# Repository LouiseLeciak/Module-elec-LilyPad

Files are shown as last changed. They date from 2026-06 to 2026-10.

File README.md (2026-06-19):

# Lily's Pad

## Overview

Lily's Pad is a simple interactive and educational object primarily intended for
children, teachers/educational teams, and families

It allows users to familiarize themselves with the alphabet and numbers in
French Sign Language (FSL) or English Sign Language (ESL), as chosen.

Lily's Pad is also accessible for hearing users who are curious or who have
hearing-impaired loved ones they would like to communicate with.

## I. Features

An LCD screen connected to a keyboard featuring letters and numbers.
A rotary encoder allowing users to scroll through FSL/ASL signs on the screen.
A clickable rotary encoder to confirm an input.
A USB Type-C port to power the device.
A power button to turn the device on/off.
A 3D-printed casing around the screen.
A 3D-printed base in which the keyboard is embedded.
A slide switch to change language, English (ASL) or French (FSL).
Two small LCD screens to display animated eyes.
Translation/game/alphabet modes.

## How to use this repository

### Generate Doxygen static website

Run the following command:

```
make doc
```

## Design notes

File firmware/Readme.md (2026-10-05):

ENGLISH VERSION BELOW

# Application principale

=================================

## Presentation

Cette application est un projet embarque developpe sur un ATmega2560.

Elle permet à l'utilisateur d'apprendre et de manipuler les signes de la LSF (Langue des Signes Française) et de la BSL (British Sign Language) grâce à une interface composee de 3 ecrans, d'un clavier matriciel et d'un encodeur rotatif.

L'application possede trois fonctionnalites principales :

- Traduction
- Alphabet
- Jeu

## Fonctionnement general

Au demarrage, le microcontrôleur initialise les differents peripheriques :

1. Les ecrans
2. Le clavier matriciel
3. Le MCP23017 lie a l'encodeur rotatif
4. Le systeme de selection de langue
5. Les differents etats de l'application

Une fois l'initialisation terminee, le menu principal est affiche.

L'application fonctionne ensuite dans une boucle principale qui verifie continuellement :

- le changement de langue.
- la rotation de l'encodeur.
- l'appui sur le bouton de l'encodeur.
- l'activite du clavier.
- le systeme d'economie d'energie .
- l'etat actuel de l'application.

Le comportement de l'interface depend principalement de machines à etats.

## Materiel

Le projet utilise principalement :

- ATmega2560 : microcontrôleur principal

- ILI9488 : ecran principal

- 2 × GC9A01 : ecrans utilises pour les yeux

- MCP23017 : pour parler en i2c au rotary encoder

- encodeur rotatif : navigation et selection

- Clavier matriciel 4 × 10 : saisie de caracteres

- Carte SD : stockage des images

- Switch : selection de la langue

## Menu principal

> Le menu principal contient trois choix :

> - Traduction

> - Alphabet

> - Jeu

L'encodeur permet de deplacer le curseur.

Le bouton permet de selectionner l'element choisi.

Le choix actuel est stocke dans menu_choice.

### Traduction

La fonctionnalite de traduction permet de saisir un mot à l'aide du clavier.

**Fonctionnement :**

- Entrer dans Traduction

- Saisir un mot

- Valider avec l'encodeur

- Afficher le signe de la premiere lettre

- Appuyer pour passer à la lettre suivante

- Afficher le signe suivant

- Continuer jusqu'à la derniere lettre

- Revenir à une nouvelle saisie

Le mot est stocke dans word et sa longueur dans word_len.

La touche “delete” permet de supprimer le dernier caractere.

Lorsque le mot est valide, le programme recherche les images correspondant aux differentes lettres sur la carte SD.

Les images dependent de la langue selectionnee.

Pour la LSF, le programme recherche les images associees au suffixe LSF.

Pour la BSL, le programme recherche les images associees au suffixe BSL.

Les images sont ensuite affichees une par une sur l'ecran principal.

----------------------------------------------------------------------
### Alphabet

La fonctionnalite Alphabet permet de parcourir les caracteres disponibles.

L'utilisateur utilise l'encodeur pour se deplacer dans la liste.

Un appui sur le bouton permet d'afficher la lettre selectionnee.

Un nouvel appui permet de revenir à la liste.

**Les deux principaux etats sont :**

ALPHABET_LIST

ALPHABET_LETTER

----------------------------------------------------------------------
### Jeux

L'application possede deux jeux.

**Jeu 1 : trouver la bonne lettre**

Le premier jeu consiste à reconnaître une lettre à partir d'un signe.

Le programme choisit aleatoirement une lettre et affiche le signe correspondant.

L'utilisateur doit ensuite choisir la bonne lettre parmi trois propositions.

Deroulement :

Signe affiche

3 propositions

Selection avec l'encodeur

Validation avec le bouton

Affichage de OUI ou NON

Une seule des trois reponses correspond au signe affiche.

Si la reponse est correcte, une nouvelle question est generee.

Si la reponse est incorrecte, le jeu revient à l'ecran de depart du jeu.

**Jeu 2 : trouver le bon signe**

Le fonctionnement est inverse.

Le programme choisit une lettre et l'affiche.

Trois signes sont ensuite presentes successivement.

Deroulement :

Lettre affichee

Signe 1

Signe 2

Signe 3

Choix entre 1, 2 et 3

Validation avec le bouton

Affichage de OUI ou NON

Une seule des trois images correspond à la lettre donnee.

Les choix et les lettres sont generes aleatoirement.

----------------------------------------------------------------------
## Encodeur rotatif

L'encodeur est connecte au MCP23017, lui-meme relie à l'ATmega2560 par I²C.

Il possede trois signaux :

**CLK** : rotation

**DT** : direction

**SW** : bouton

La rotation permet de deplacer les curseurs dans les differents menus.

Le bouton permet de valider ou de passer à l'etape suivante.

Le comportement de l'encodeur depend de l'etat actuel de l'application.

Par exemple :

Dans le MENU, l'encodeur deplace le curseur du menu.

Dans l'ALPHABET, il permet de parcourir les lettres.

Dans le JEU, il permet de sectelionner une reponse.

Le bouton possede egalement un systeme d'anti-rebond afin d'eviter plusieurs detections pour un seul appui.

## Clavier

Le clavier est une matrice de 4 lignes et 10 colonnes, soit 38 touches.

La disposition utilisee est :

1 2 3 4 5 6 7 8 9 0

Q W E R T Y U I O P

A S D F G H J K L -

Z X C V B N M # /

Le '#' est pour le retour a l'ecran principal, '/' pour supprimer.

Le programme selectionne chaque ligne successivement et lit les colonnes afin de detecter la touche appuyee.

Le tableau keymap permet ensuite de convertir la position de la touche en caractere.

## Gestion de la langue

Deux langues sont disponibles :

LANG_FR

LANG_EN

La langue est selectionnee grâce à un switch materiel.

La variable language permet de connaître la langue actuellement utilisee.

Les textes affiches et les images recherchees dependent de cette langue.

## Gestion de l'energie

L'application possede un systeme d'economie d'energie.

Lorsqu'aucune interaction n'est detectee pendant un certain temps, l'application passe en veille.

Le retroeclairage de l'ecran principal est alors desactive et les yeux changent d'affichage.

Une activite de l'utilisateur reactive le systeme.

Les principales actions considerees comme une activite sont :

- rotation de l'encodeur
- appui sur le bouton
- appui sur une touche du clavier
- changement de langue

La fonction power_save_activity() remet le systeme en activite.

La fonction power_save_update() gere le compteur d'inactivite, apres une 20aine de secondes on passe en economie d’energie.

### Architecture du code

Le projet est organise en plusieurs modules.

Le dossier app contient la logique principale de l'application :

- menu

- traduction

- alphabet

- game

Le dossier display contient la gestion des ecrans :

- ILI9488

- GC9A01

- affichage du texte

Le dossier input contient la gestion des entrees :

- clavier

- encodeur

- I²C / MCP23017

Le dossier system contient les elements communs au systeme :

- globals

- power_save

- Le dossier utils contient les fonctions utilitaires.

- Chaque module possede une responsabilite specifique.

- Les modules app gerent la logique de l'application.

- Les modules input gerent les interactions avec l'utilisateur.

- Les modules display gerent les ecrans.

- Les modules system regroupent les elements communs au fonctionnement du systeme.

- Machine à etats

- Le fonctionnement de l'application repose sur plusieurs niveaux d'etats.

- L'etat principal est app_state.

Il permet de savoir si l'utilisateur se trouve dans :

MENU

TRADUCTION

ALPHABET

JEU

Chaque fonctionnalite possede ensuite ses propres etats.

Par exemple, pendant un jeu :

- Afficher la question

- Afficher les propositions

- Selectionner une reponse

- Valider

- Afficher OUI ou NON

- Passer à la question suivante

Cette organisation permet au meme bouton ou au meme mouvement de l'encodeur d'avoir un comportement different selon la situation.

## Boucle principale

La boucle principale permet à l'application de surveiller en permanence les entrees utilisateur et de faire evoluer la machine à etats.

Elle gere notamment :

- la langue

- le generateur aleatoire 

- l'encodeur 

- le bouton de l'encodeur 

- l'economie d'energie 

- le clavier 

- la fonctionnalite actuellement selectionnee.

## Resume

L'application est organisee autour de trois elements principaux.

**Entrees :**

- Clavier matriciel

- Encodeur rotatif

- Bouton de l'encodeur

- Switch de langue

**Traitement :**

- Machines à etats

- Navigation dans les menus

- Gestion de la traduction

- Gestion de l'alphabet

- Gestion des jeux

- Generation aleatoire

- Gestion de l'economie d'energie

**Sorties :**

- Ecran ILI9488

- Deux ecrans GC9A01

- Images de signes stockees sur carte SD

Le systeme utilise principalement une architecture basee sur les etats. Cela permet de gerer les differentes fonctionnalites de l'application et d'adapter le comportement du clavier, de l'encodeur et du bouton en fonction de l'ecran ou de l'action en cours.

-------------------------------------------------------------------------------------------------------

# Primary Application

=================================

## Presentation

This application is a project developed on an ATmega2560.

It allows the user to learn and manipulate the signs of LSF (French Sign Language) and BSL (British Sign Language) thanks to an interface composed of 3 screens, a matrix keyboard and a rotary encoder.

The application has three main functionalities:

- Translation
- Alphabet
- Game

## General operation

At startup, the microcontroller initializes the different devices:

1. The screens
2. The matrix keyboard
3. The MCP23017 is connected to the rotary encoder
4. The language selection system
5. The different states of the application

Once the initialization is complete, the main menu appears.

The application then runs in a main loop that continuously checks:

- the change of language.
- the encoder rotation.
- pressing the encoder button.
- the keyboard activity.
- the energy-saving system.
- the current status of the application.

The behavior of the interface mainly depends on state machines.

## Hardware

The project mainly uses:

- ATmega2560: Primary microcontroller

- ILI9488: main screen

- 2 × GC9A01: screens used for the eyes

- MCP23017: to speak in i2c at the rotary encoder

- rotary encoder: navigation and selection

- Matrix keyboard 4 × 10: character input

- SD card: image storage

- Switch: language selection

## Main Menu

> The main menu contains three choices:

> - Translation

> - Alphabet

> - Game

The encoder allows you to move the cursor.

The button allows you to select the chosen element.

The current choice is stored in menu_choice.

### Translation

Translation functionality allows you to enter a word using the keyboard.

**Operation:***

- Enter Translation

- Enter a word

- Validate with the encoder

- Display the sign of the first letter

- Press to move on to the next letter

- Display the following sign

- Continue until the last letter

- Return to a new entry

The word is stored in word and its length in word_len.

The key "delete" allows to delete the last character.

When the word is valid, the program searches for images corresponding to the different letters on the SD card.

The images dependent on the selected language.

For LSF, the program searches for images associated with the LSF suffix.

For the BSL, the program searches for images associated with the BSL suffix.

The images are then displayed one by one on the main screen.

----------------------------------------------------------------------
### Alphabet

The Alphabet functionality allows you to browse through the available characters.

The user uses the encoder to move into the list.

Pressing the button displays the selected letter.

A new tap allows you to return to the list.

**The two main states are:***

ALPHABET_LIST

ALPHABET_LETTER

----------------------------------------------------------------------
### Games

The app has two games.

**Game 1: find the right letter**

The first game is to recognize a letter from a sign.

The program randomly chooses a letter and displays the corresponding sign.

The user must then choose the correct letter from among three proposals.

Layout:

Poster sign

3 proposals

Selection with the encoder

Validation with the button

Display YES or NO

Only one of the three answers corresponds to the poster sign.

If the answer is correct, a new question is generated.

If the answer is incorrect, the game returns to the game’s start screen.

**Game 2: find the right sign**

The operation is reversed.

The program chooses a letter and displays it.

Three signs are then presented successively.

Layout:

Letter displayed

Sign 1

Sign 2

Sign 3

Choice between 1, 2, and 3

Validation with the button

Display YES or NO

Only one of the three images corresponds to the given letter.

Choices and letters are randomly generated.

----------------------------------------------------------------------
## Rotary encoder

The encoder is connected to the MCP23017, which in turn is connected to the ATmega2560 by I 2 C.

He has three signals:

**CLK** : rotation

**DT** : management

**SW** : button

Rotation allows you to move the cursors in different menus.

The button allows you to validate or move on to the next step.

The encoder behavior depends on the current state of the application.

For example:

In the MENU, the encoder moves the menu cursor.

In the ALPHABET, it allows you to move through the letters.

In the GAME, it allows you to select a response.

The button also has an anti-bounce system to avoid several detections for a single touch.

## Keyboard

The keyboard is a matrix of 4 rows and 10 columns, or 38 keys.

The layout used is:

1 2 3 4 5 6 7 8 9 0

Q W E R T Y U I O P

A S D F G H J K L

Z X C V B N M # /

'#' is for HOME and '/' is for delete.

The program selects each row successively and reads the columns in order to detect the key pressed.

The keymap table then allows you to convert the key position into a character.

## Language Management

Two languages are available:

LANG_FR

LANG_EN

The language is selected thanks to a hardware switch.

The language variable lets you know which language is currently in use.

The poster texts and images sought after in this language.

## Energy Management

The application has an energy-saving system.

When no interaction is detected for a period of time, the application goes into standby.

The backlighting of the main screen is then deactivated and the eyes change their display.

An activity of the user reactivates the system.

The main actions considered as an activity are:

- rotation of the encoder
- press the button
- press a key on the keyboard
- change of language

The power_save_activity() function restarts the system.

The power_save_update() function manages the inactivity counter, after about 20 seconds you switch to power saving.

### Code Architecture

The project is organized into several modules.

The app folder contains the main logic of the application:

- menu

- translation

- alphabet

- game

The display folder contains screen management:

- ILI9488

- GC9A01

- displaying the text

The input folder contains the management of entries:

- keyboard

- encoder

- I 2 C / MCP23017

The system folder contains the common elements of the system:

- globals

- power_save

- The utils folder contains the utility functions.

- Each module has a specific responsibility.

- The app modules manage the logic of the application.

- The input modules manage interactions with the user.

- The display modules handle the screens.

- The system modules bring together the common elements of the system’s operation.

- State machine

- The operation of the application is based on several levels of states.

- The main state is app_state.

It lets you know if the user is located in:

**MENU**

**TRANSLATION**

**ALPHABET**

**GAME**

Each functionality then has its own states.

For example, during a game:

- View the question

- View the proposals

- Select a response

- Validate

- Show YES or NO

- Move on to the next question

This organization allows the same button or the same movement of the encoder to have a different behavior depending on the situation.

## Main loop

The main loop allows the application to constantly monitor user inputs and to make the state machine evolve.

She manages in particular:

- the language

- the random generator 

- the encoder 

- the encoder button 

- energy saving 

- the keyboard 

- the functionality currently selected.

## Resume

The application is organized around three main elements.

**Entries:**

- Matrix keyboard

- Rotary encoder

- Encoder button

- Switch language

**Treatment:**

- State machines

- Menu navigation

- Translation management

- Management of the alphabet

- Game management

- Random generation

- Energy saving management

**Outings:**

- Screen ILI9488

- Two GC9A01 screens

- Sign images stored on an SD card

The system mainly uses a state-based architecture. This allows to manage the different functionalities of the application and to adapt the behavior of the keyboard, the encoder and the button according to the screen or the current action.

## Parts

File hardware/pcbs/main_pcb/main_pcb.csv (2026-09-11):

Reference | Qty | Value | DNP | Exclude from BOM | Exclude from Board | Footprint | Datasheet
C1,C2,C5,C6,C7,C21,C22,C23,C24,C25,C26,C27,C28,C29,C30,C31,C32,C33 | 18 | 100nF
C3,C4 | 2 | 33pF
C8,C9 | 2 | 0.1uF
C20 | 1 | 10uF
J1,J3,S2,U1,U15,U17,Y1 | 7 | ~ |  |  |  |  | file:///Users/apetitco/Documents/Module Elec - Lily's Pad/Datasheets/U - Integrated Circuits/MCU/ATmega_2560.pdf,file:///Users/apetitco/Documents/Module Elec - Lily's Pad/Datasheets/U - Integrated Circuits/Screen Drivers/GC9A01A.pdf,file:///Users/apetitco/Documents/Module Elec - Lily's Pad/Datasheets/Y - Crystals and Oscillators/SOSET_S47SMD16.000M20PF20R30B3.pdf
J2 | 1 | USB-C |  |  |  |  | file:///Users/apetitco/Documents/Module Elec - Lily's Pad/Datasheets/U - Integrated Circuits/Voltage Regulators/JSMSEMI_AMS1117-3.3V.pdf
J4 | 1 | 2X4 Header
R1,R8,R9,R10,R11 | 5 | 10kΩ
R2,R3 | 2 | 5.1kΩ
U8 | 1 | CH340C |  |  |  | lilys_pad:CH340C | file:///Users/apetitco/Documents/Module Elec - Lily's Pad/Datasheets/U - Integrated Circuits/CH340C.pdf
U10 | 1 | JSMSEMI AMS1117-3.3V |  |  |  |  | file:///Users/apetitco/Documents/Module Elec - Lily's Pad/Datasheets/U - Integrated Circuits/Voltage Regulators/JSMSEMI_AMS1117-3.3V.pdf
U11,U13,U16 | 3 | TI TXB0104DR |  |  |  |  | file:///home/apetitco/Documents/school/42Chips/module/Datasheets/U - Integrated Circuits/Level Shifters/7ebf70d32255e71aa643aae8d62d2a45.pdf
U12 | 1 | ILI9488
U14 | 1 | SD Card Socket

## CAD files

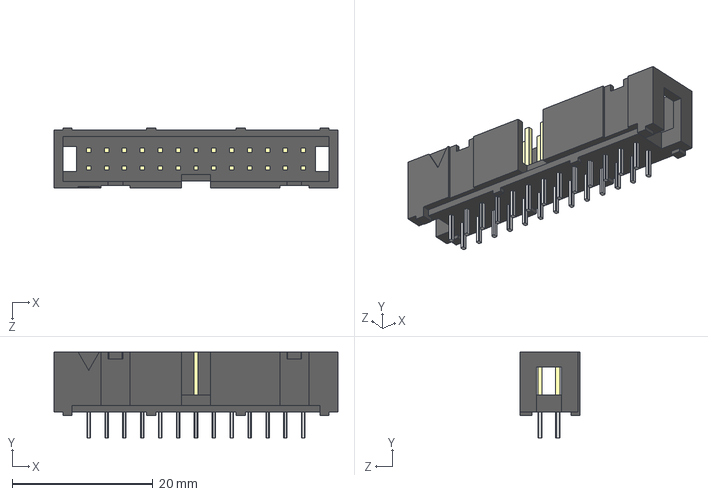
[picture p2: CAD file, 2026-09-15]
hardware/kicad_libraries/3D Models/XG4C-2631--3DModel-STEP-273799.STEP
40.3 x 12.2 x 8.50 mm

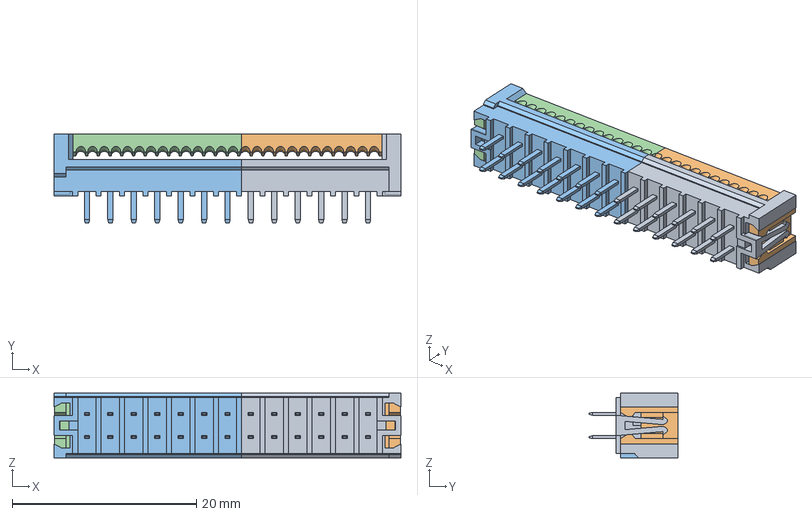
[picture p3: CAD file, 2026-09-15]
hardware/kicad_libraries/3D Models/69830-026LF--3DModel-STEP-533217.STEP
37.6 x 9.65 x 7.00 mm
69830_20P_BODY_1_AF0_1_AF0_1
69830_20P_COVER_1_AF0_1_AF0_1
69830_20P_BODY_1_AF0_1
69830_20P_COVER_1_AF0_1

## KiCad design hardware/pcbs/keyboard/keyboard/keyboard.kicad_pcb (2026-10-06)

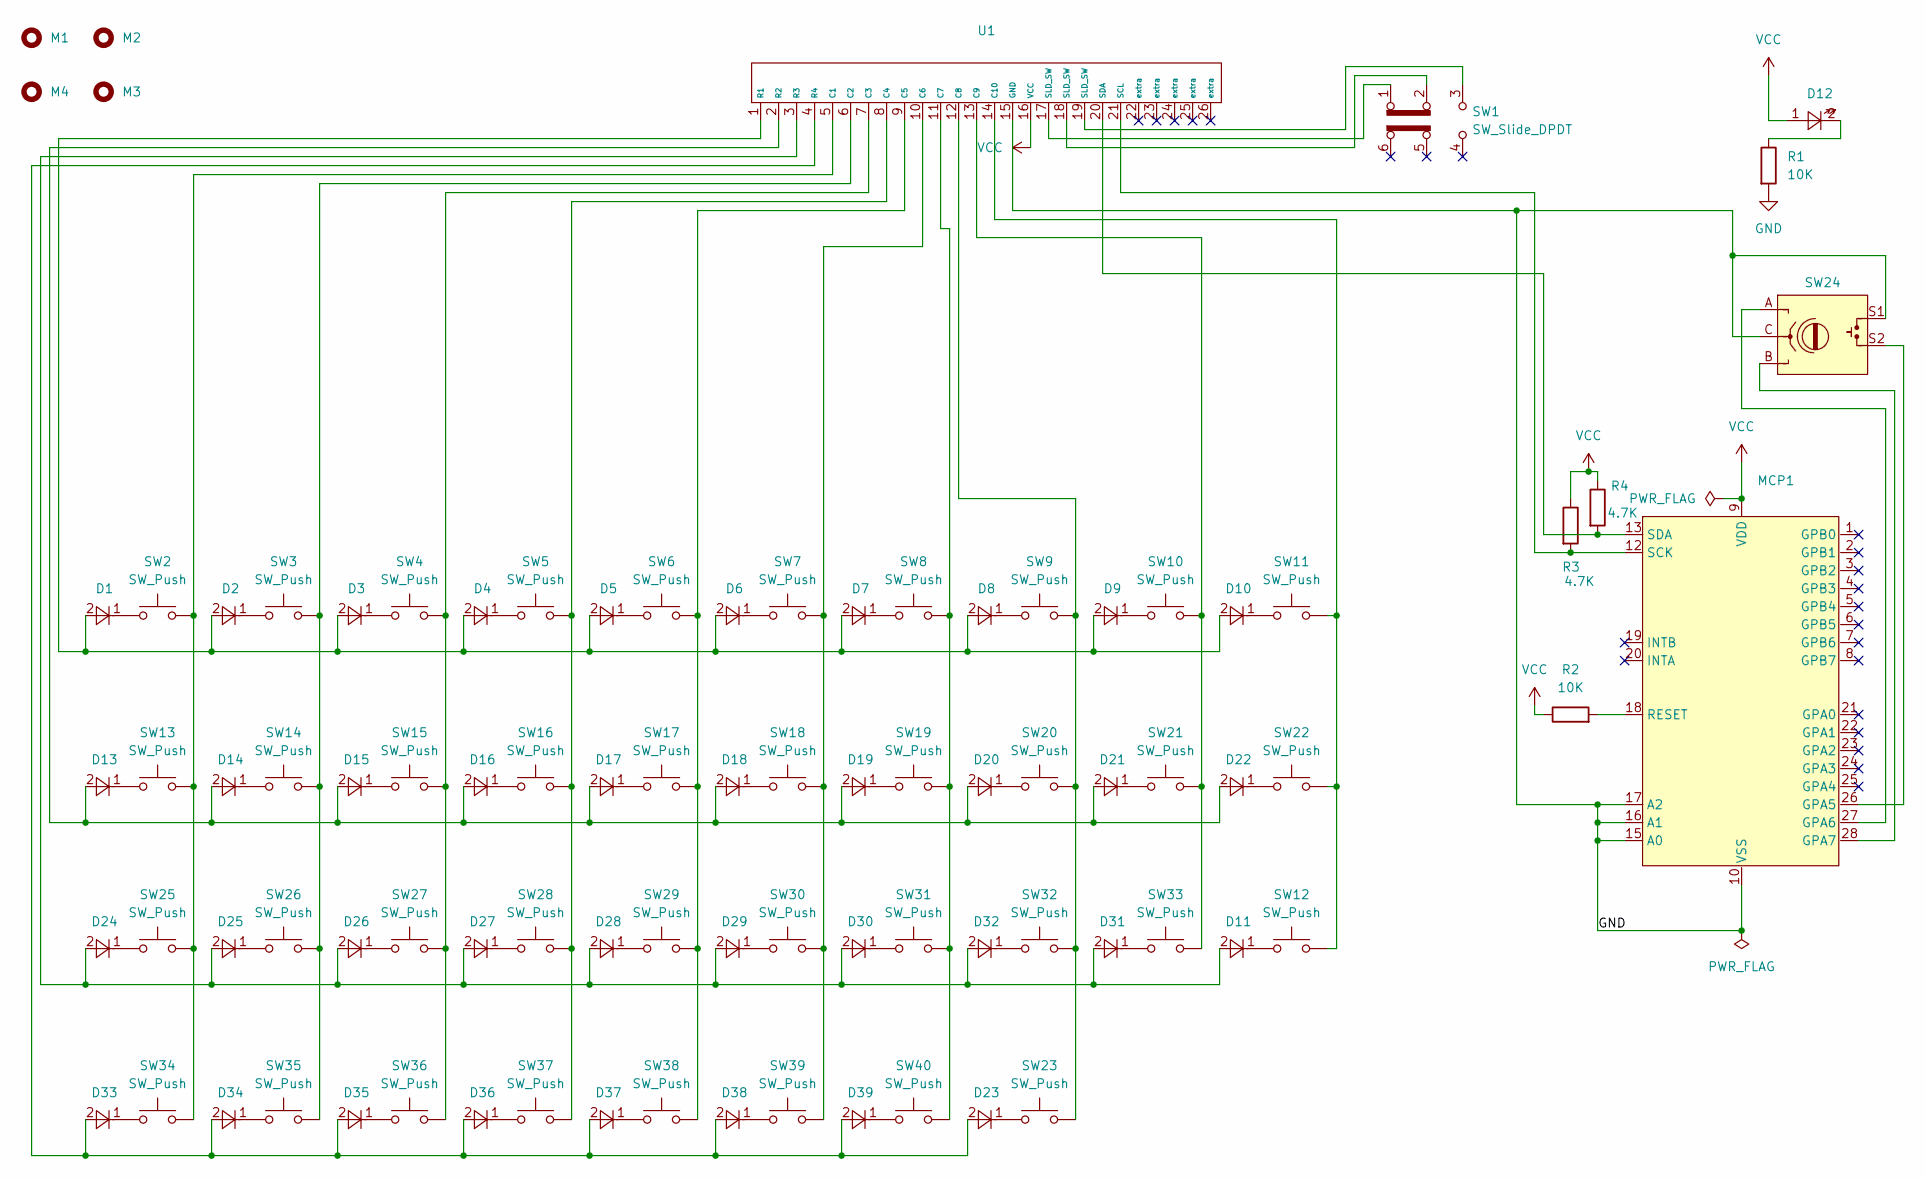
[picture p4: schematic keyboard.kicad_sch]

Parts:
D1, D2, D3, D4, D5, D6, D7, D8, D9, D10, D11, D13, D14, D15, D16, D17, D18, D19, D20, D21, D22, D23, D24, D25, D26, D27, D28, D29, D30, D31, D32, D33, D34, D35, D36, D37, D38, D39: diode
D12: led
M1, M2, M3, M4: hole
MCP1: MCP23017
R1, R2: 10K; Resistance
R3, R4: 4.7K; Resistance
SW1: SW_Slide_DPDT; slide_switch
SW2, SW3, SW4, SW5, SW6, SW7, SW8, SW9, SW10, SW11, SW12, SW13, SW14, SW15, SW16, SW17, SW18, SW19, SW20, SW21, SW22, SW23, SW25, SW26, SW27, SW28, SW29, SW30, SW31, SW32, SW33, SW34, SW35, SW36, SW37, SW38, SW39, SW40: SW_Push; push_switch
SW24: rotary_encoder
U1: male_header

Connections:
GND: MCP1.10 (VSS), MCP1.15 (A0), MCP1.16 (A1), MCP1.17 (A2), R1.2, SW24.C, SW24.S1, U1.15 (GND)
unnamed: D1.1, SW2.1
unnamed: D2.1, SW3.1
unnamed: D3.1, SW4.1
unnamed: D4.1, SW5.1
unnamed: D5.1, SW6.1
unnamed: D6.1, SW7.1
unnamed: D7.1, SW8.1
unnamed: D8.1, SW9.1
unnamed: D9.1, SW10.1
unnamed: D10.1, SW11.1
unnamed: D11.1, SW12.1
unnamed: D12.2, R1.1
unnamed: D13.1, SW13.1
unnamed: D14.1, SW14.1
unnamed: D15.1, SW15.1
unnamed: D16.1, SW16.1
unnamed: D17.1, SW17.1
unnamed: D18.1, SW18.1
unnamed: D19.1, SW19.1
unnamed: D20.1, SW20.1
unnamed: D21.1, SW21.1
unnamed: D22.1, SW22.1
unnamed: D23.1, SW23.1
unnamed: D24.1, SW25.1
unnamed: D25.1, SW26.1
unnamed: D26.1, SW27.1
unnamed: D27.1, SW28.1
unnamed: D28.1, SW29.1
unnamed: D29.1, SW30.1
unnamed: D30.1, SW31.1
unnamed: D31.1, SW33.1
unnamed: D32.1, SW32.1
unnamed: D33.1, SW34.1
unnamed: D34.1, SW35.1
unnamed: D35.1, SW36.1
unnamed: D36.1, SW37.1
unnamed: D37.1, SW38.1
unnamed: D38.1, SW39.1
unnamed: D39.1, SW40.1
unnamed: MCP1.26 (GPA5), SW24.S2
unnamed: MCP1.27 (GPA6), SW24.A
unnamed: MCP1.28 (GPA7), SW24.B
unnamed: MCP1.18 (RESET), R2.2
unnamed: MCP1.12 (SCK), R3.2, U1.21 (SCL)
unnamed: MCP1.13 (SDA), R4.2, U1.20 (SDA)
unnamed: SW1.1 (A), U1.17 (SLD_SW)
unnamed: SW1.2 (B), U1.18 (SLD_SW)
unnamed: SW1.3 (C), U1.19 (SLD_SW)
unnamed: SW2.2, SW13.2, SW25.2, SW34.2, U1.5 (C1)
unnamed: SW3.2, SW14.2, SW26.2, SW35.2, U1.6 (C2)
unnamed: SW4.2, SW15.2, SW27.2, SW36.2, U1.7 (C3)
unnamed: SW5.2, SW16.2, SW28.2, SW37.2, U1.8 (C4)
unnamed: SW6.2, SW17.2, SW29.2, SW38.2, U1.9 (C5)
unnamed: SW7.2, SW18.2, SW30.2, SW39.2, U1.10 (C6)
unnamed: SW8.2, SW19.2, SW31.2, SW40.2, U1.11 (C7)
unnamed: SW9.2, SW20.2, SW23.2, SW32.2, U1.12 (C8)
unnamed: SW10.2, SW21.2, SW33.2, U1.13 (C9)
unnamed: SW11.2, SW12.2, SW22.2, U1.14 (C10)
unnamed: D1.2, D2.2, D3.2, D4.2, D5.2, D6.2, D7.2, D8.2, D9.2, D10.2, U1.1 (R1)
unnamed: D13.2, D14.2, D15.2, D16.2, D17.2, D18.2, D19.2, D20.2, D21.2, D22.2, U1.2 (R2)
unnamed: D11.2, D24.2, D25.2, D26.2, D27.2, D28.2, D29.2, D30.2, D31.2, D32.2, U1.3 (R3)
unnamed: D23.2, D33.2, D34.2, D35.2, D36.2, D37.2, D38.2, D39.2, U1.4 (R4)
VCC: D12.1, MCP1.9 (VDD), R2.1, R3.1, R4.1, U1.16 (VCC)

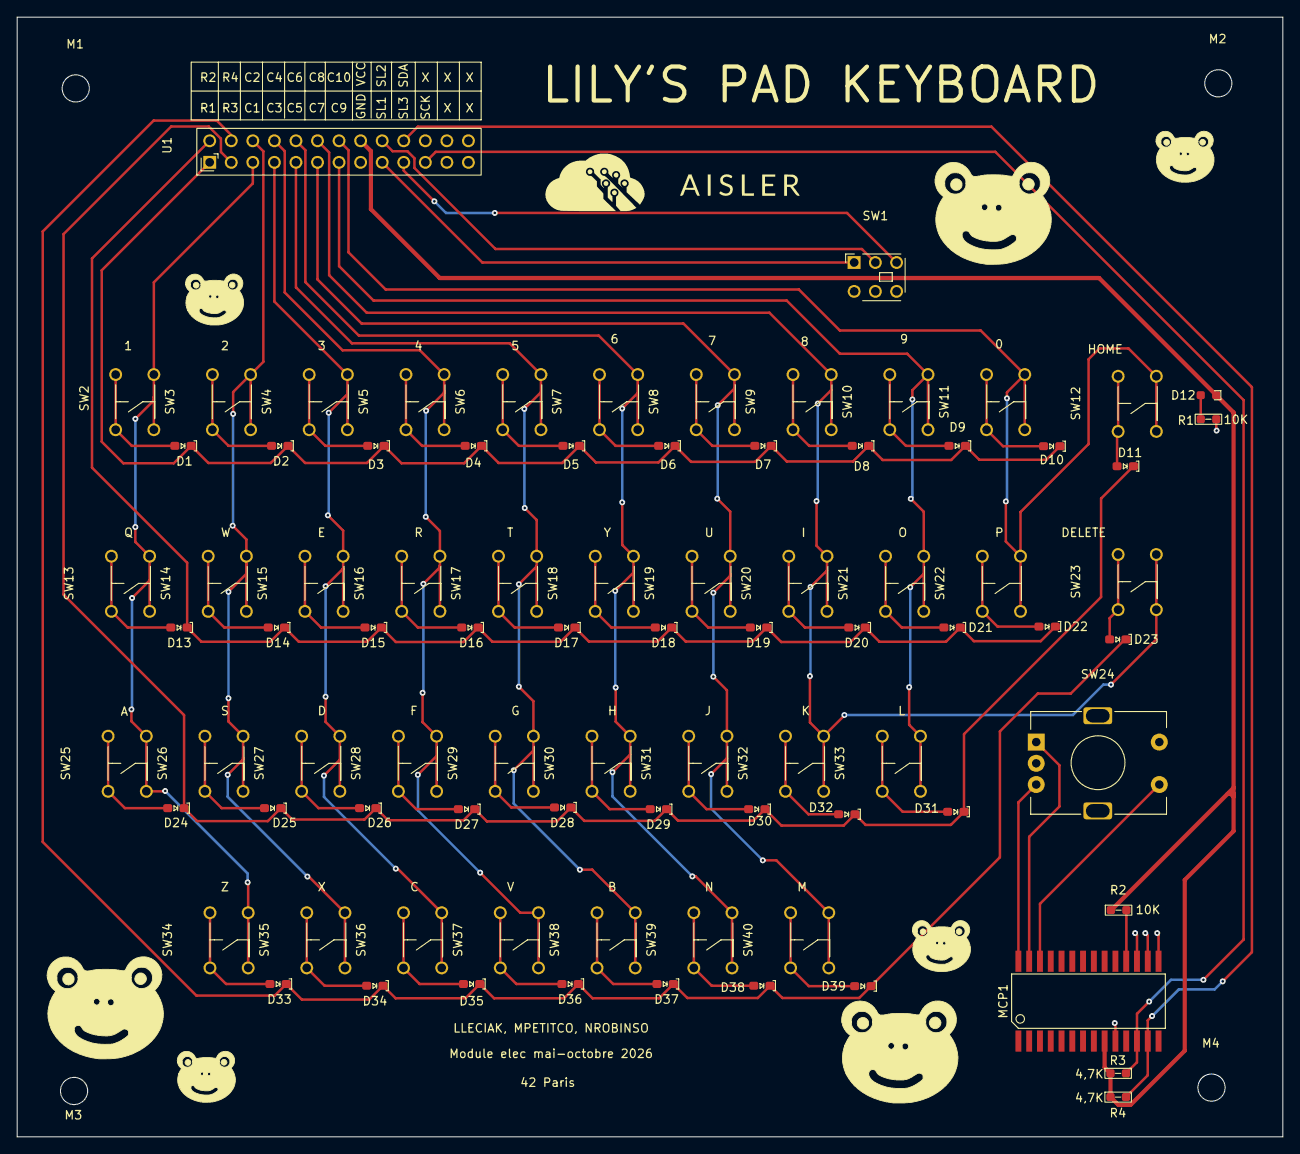
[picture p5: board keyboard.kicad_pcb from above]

Board: 2 copper layers, 149.1 x 131.9 mm, 89 parts (0 on the bottom side), 64 nets.

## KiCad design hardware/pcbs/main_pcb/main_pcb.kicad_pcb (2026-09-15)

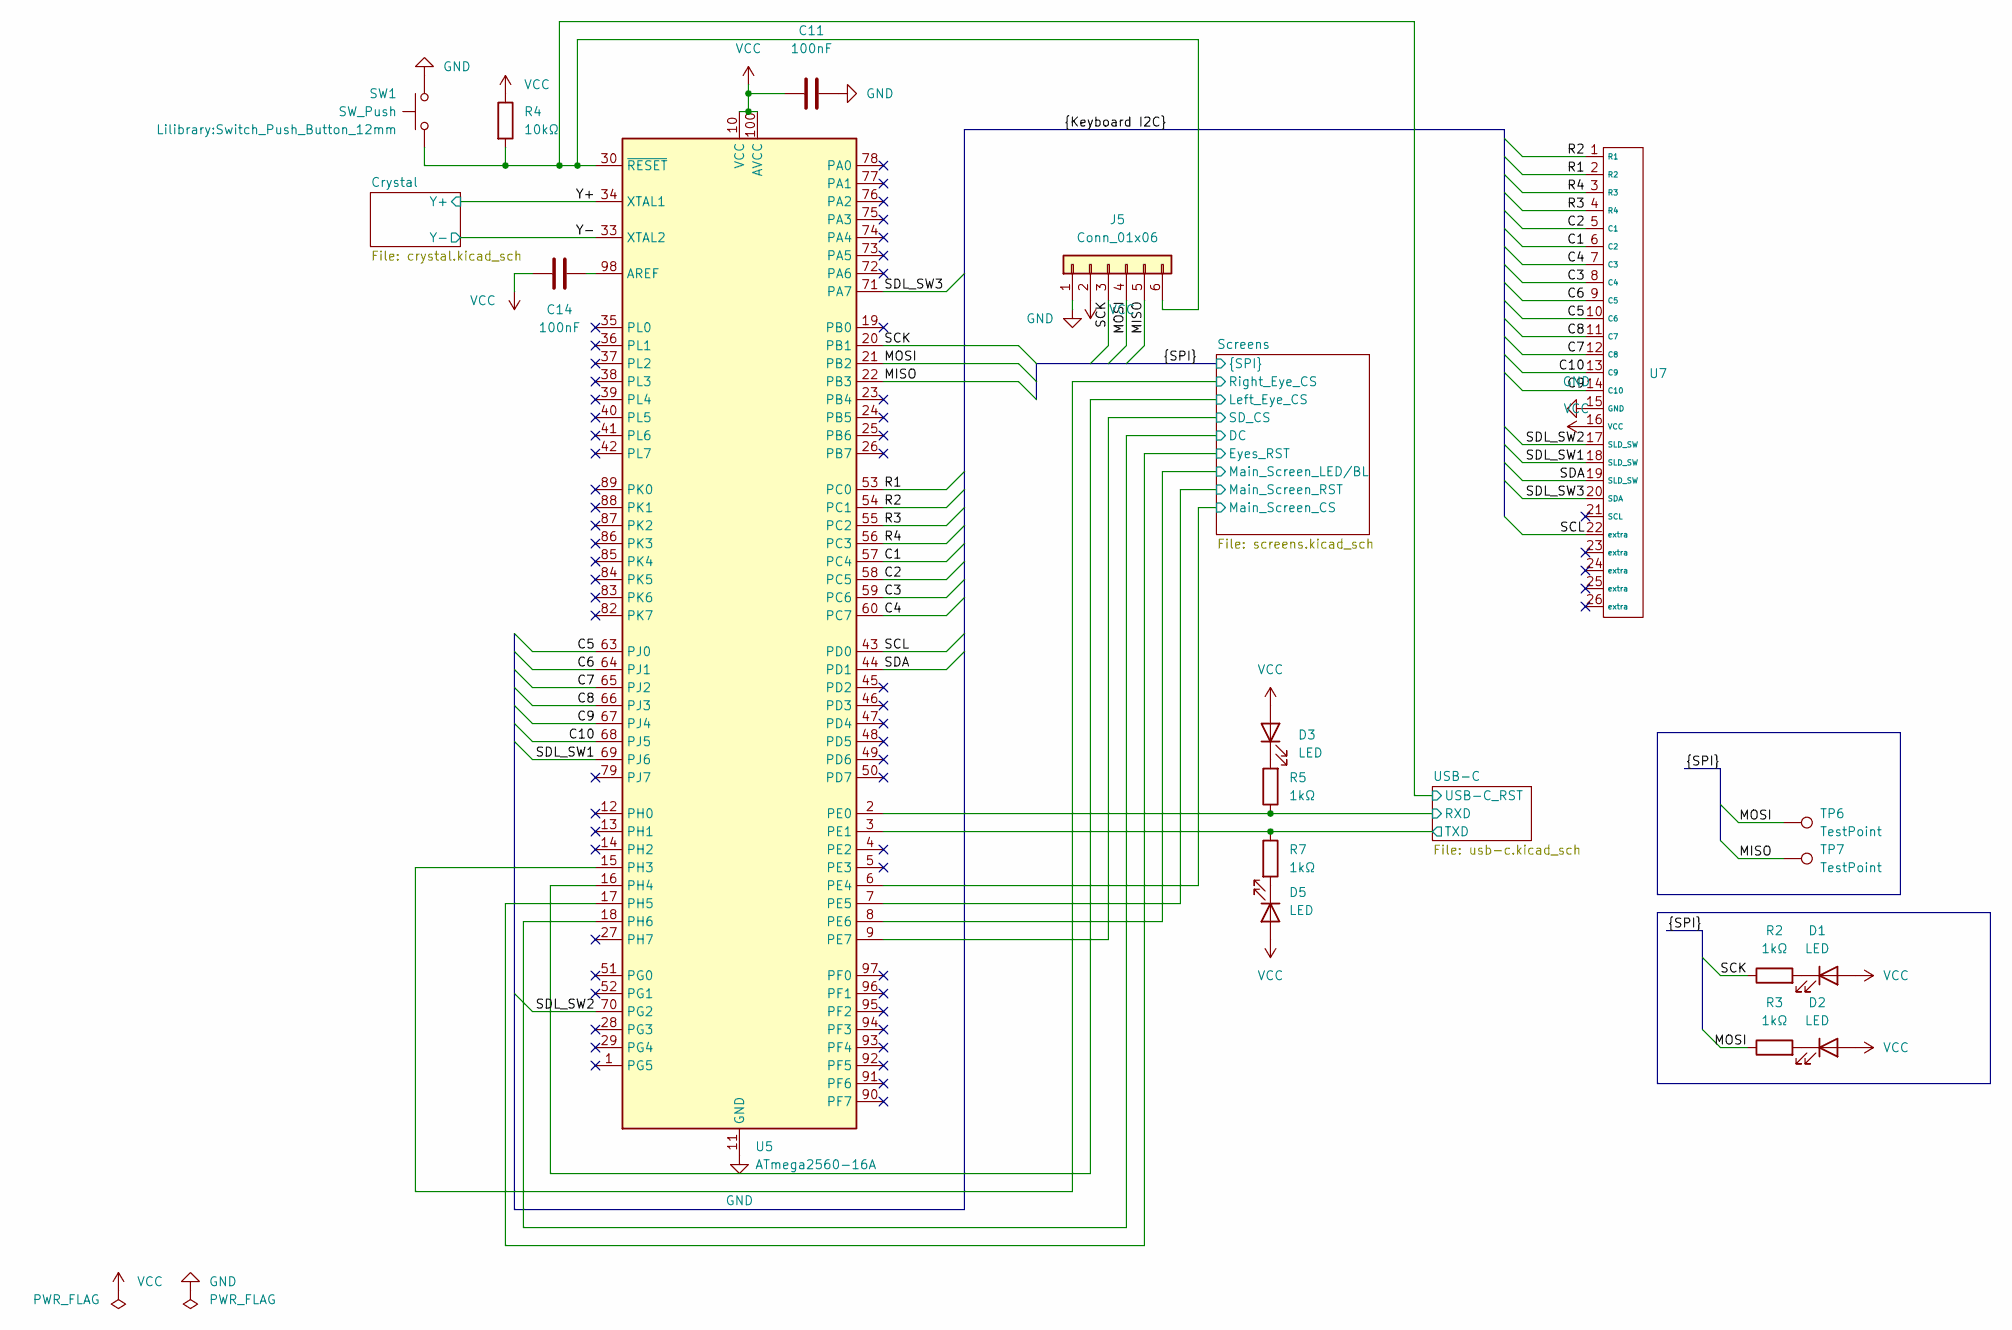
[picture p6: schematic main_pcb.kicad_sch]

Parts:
C11, C14: 100nF; Capacitor_0603; LCSC C14663
D1, D2, D3, D5: LED; LED_0603; LCSC C19171394
J5: Conn_01x06; Pin_1x06_2.54mm_Vertical
R2, R3, R5, R7: 1kΩ; Resistor_0603; LCSC C22548
R4: 10kΩ; Resistor_0603; LCSC C98220
SW1: SW_Push; Switch_Push_Button_12mm; LCSC C84931
TP6, TP7: TestPoint; Test point
U5: ATmega2560-16A; TQFP-100_14x14mm_P0.5mm; LCSC C22460
U7: AMPHENOL_69830-026LF; LCSC C397108

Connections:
/C1: U5.57 (PC4), U7.6 (C2)
/C2: U5.58 (PC5), U7.5 (C1)
/C3: U5.59 (PC6), U7.8 (C4)
/C4: U5.60 (PC7), U7.7 (C3)
/C5: U5.63 (PJ0), U7.10 (C6)
/C6: U5.64 (PJ1), U7.9 (C5)
/C7: U5.65 (PJ2), U7.12 (C8)
/C8: U5.66 (PJ3), U7.11 (C7)
/C9: U5.67 (PJ4), U7.14 (C10)
/C10: U5.68 (PJ5), U7.13 (C9)
/MISO: J5.5, TP7.1, U5.22 (PB3); also elsewhere on the board
/MOSI: J5.4, R3.1, TP6.1, U5.21 (PB2); also elsewhere on the board
/R1: U5.53 (PC0), U7.2 (R2)
/R2: U5.54 (PC1), U7.1 (R1)
/R3: U5.55 (PC2), U7.4 (R4)
/R4: U5.56 (PC3), U7.3 (R3)
/SCK: J5.3, R2.1, U5.20 (PB1); also elsewhere on the board
/SCL: U5.43 (PD0), U7.22 (extra)
/SDA: U5.44 (PD1), U7.19 (SLD_SW)
/SDL_SW1: U5.69 (PJ6), U7.18 (SLD_SW)
/SDL_SW2: U5.70 (PG2), U7.17 (SLD_SW)
/SDL_SW3: U5.71 (PA7), U7.20 (SDA)
/Screens/DC: U5.18 (PH6); also elsewhere on the board
/Screens/Eyes_RST: U5.17 (PH5); also elsewhere on the board
/Screens/Left_Eye_CS: U5.16 (PH4); also elsewhere on the board
/Screens/Main_Screen_CS: U5.6 (PE4); also elsewhere on the board
/Screens/Main_Screen_LED/BL: U5.8 (PE6); also elsewhere on the board
/Screens/Main_Screen_RST: U5.7 (PE5); also elsewhere on the board
/Screens/Right_Eye_CS: U5.15 (PH3); also elsewhere on the board
/Screens/SD_CS: U5.9 (PE7); also elsewhere on the board
/USB-C/RXD: R5.1, U5.2 (PE0); also elsewhere on the board
/USB-C/TXD: R7.1, U5.3 (PE1); also elsewhere on the board
/USB-C/USB-C_RST: J5.6, R4.2, SW1.1, U5.30 (~RESET); also elsewhere on the board
/Y+: U5.34 (XTAL1); also elsewhere on the board
/Y-: U5.33 (XTAL2); also elsewhere on the board
GND: C11.2, J5.1, SW1.2, U5.11 (GND), U5.32 (GND), U5.62 (GND), U5.81 (GND), U5.99 (GND), U7.15 (GND); also elsewhere on the board
unnamed: D1.1 (K), R2.2
unnamed: D2.1 (K), R3.2
unnamed: D3.1 (K), R5.2
unnamed: D5.1 (K), R7.2
unnamed: C14.2, U5.98 (AREF)
VCC: C11.1, C14.1, D1.2 (A), D2.2 (A), D3.2 (A), D5.2 (A), J5.2, R4.1, U5.10 (VCC), U5.31 (VCC), U5.61 (VCC), U5.80 (VCC), U5.100 (AVCC), U7.16 (VCC); also elsewhere on the board

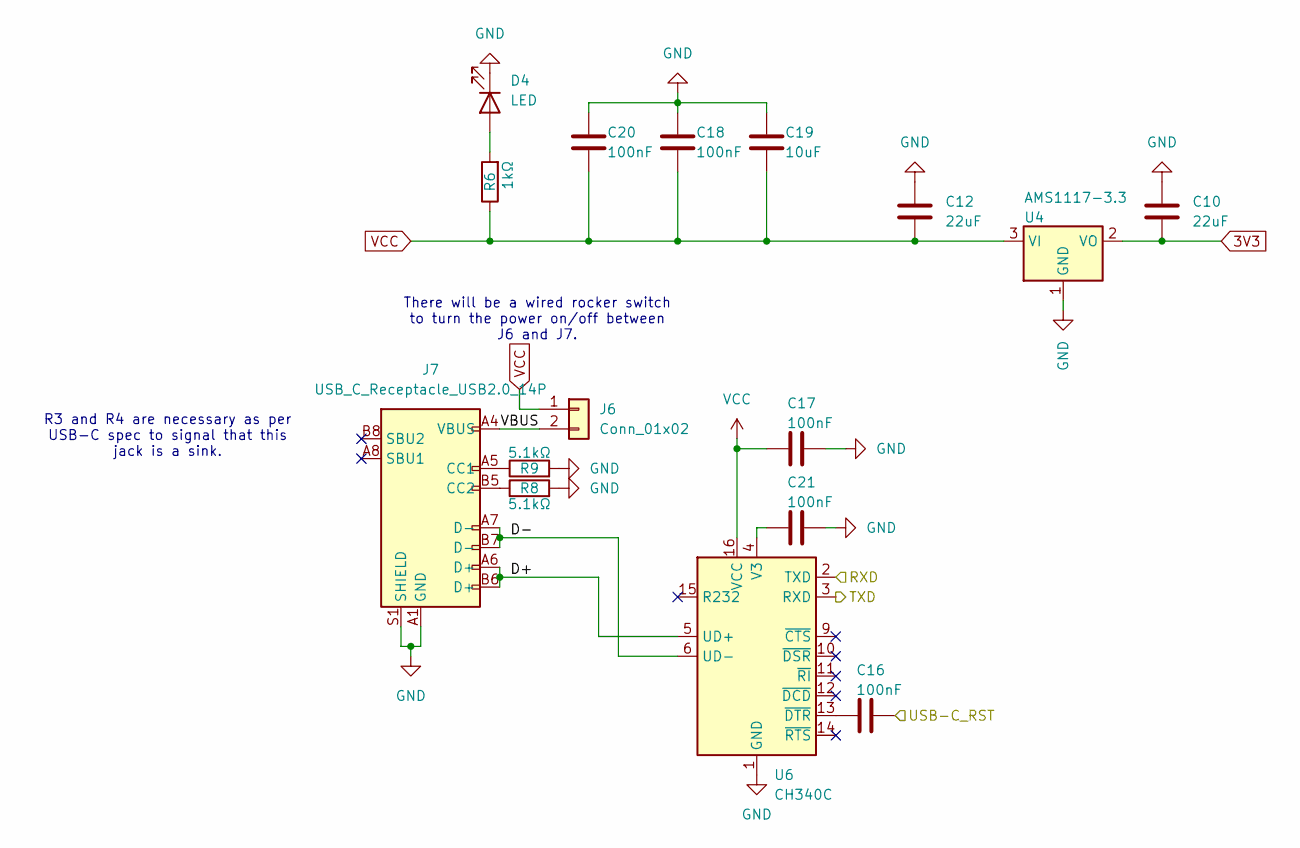
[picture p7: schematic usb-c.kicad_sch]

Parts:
C10, C12: 22uF; Capacitor_0603; LCSC C2762594
C16, C17, C18, C20, C21: 100nF; Capacitor_0603; LCSC C14663
C19: 10uF; Capacitor_0603; LCSC C1691
D4: LED; LED_0603; LCSC C19171394
J6: Conn_01x02; JST XH 2 pins
J7: USB_C_Receptacle_USB2.0_14P; USB_C_Receptacle_HRO_TYPE-C-31-M-12; LCSC C165948
R6: 1kΩ; Resistor_0603; LCSC C22548
R8, R9: 5.1kΩ; Resistor_0603; LCSC C2907044
U4: AMS1117-3.3; SOT-223-3_TabPin2; LCSC C5205141
U6: CH340C; SOIC-16_3.9x9.9mm_P1.27mm; LCSC C84681

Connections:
3V3: C10.2, U4.2 (VO); also elsewhere on the board
/USB-C/D+: J7.A6 (D+), J7.B6 (D+), U6.5 (UD+)
/USB-C/D-: J7.A7 (D-), J7.B7 (D-), U6.6 (UD-)
/USB-C/RXD: U6.2 (TXD); also elsewhere on the board
/USB-C/TXD: U6.3 (RXD); also elsewhere on the board
/USB-C/USB-C_RST: C16.2; also elsewhere on the board
/USB-C/VBUS: J6.2, J7.A4 (VBUS), J7.A9 (VBUS), J7.B4 (VBUS), J7.B9 (VBUS)
GND: C10.1, C12.1, C17.2, C18.1, C19.1, C20.1, C21.2, D4.1 (K), J7.A1 (GND), J7.A12 (GND), J7.B1 (GND), J7.B12 (GND), J7.S1 (SHIELD), R8.2, R9.2, U4.1 (GND), U6.1 (GND); also elsewhere on the board
unnamed: D4.2 (A), R6.2
unnamed: J7.A5 (CC1), R9.1
unnamed: J7.B5 (CC2), R8.1
unnamed: C21.1, U6.4 (V3)
unnamed: C16.1, U6.13 (~DTR)
VCC: C12.2, C17.1, C18.2, C19.2, C20.2, J6.1, R6.1, U4.3 (VI), U6.16 (VCC); also elsewhere on the board

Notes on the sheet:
R3 and R4 are necessary as per USB-C spec to signal that this jack is a sink.
There will be a wired rocker switch to turn the power on/off between J6 and J7.

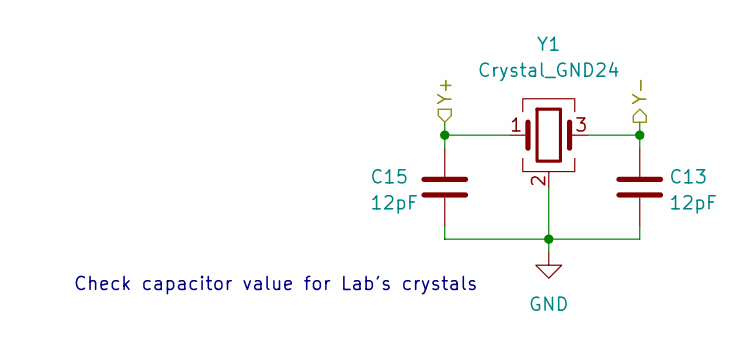
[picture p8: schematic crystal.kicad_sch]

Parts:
C13, C15: 12pF; Capacitor_0603; LCSC C107034
Y1: Crystal_GND24; Crystal_3225; LCSC C13738

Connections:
/Y+: C15.2, Y1.1; also elsewhere on the board
/Y-: C13.2, Y1.3; also elsewhere on the board
GND: C13.1, C15.1, Y1.2 (G), Y1.4 (G); also elsewhere on the board

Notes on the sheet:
Check capacitor value for Lab's crystals

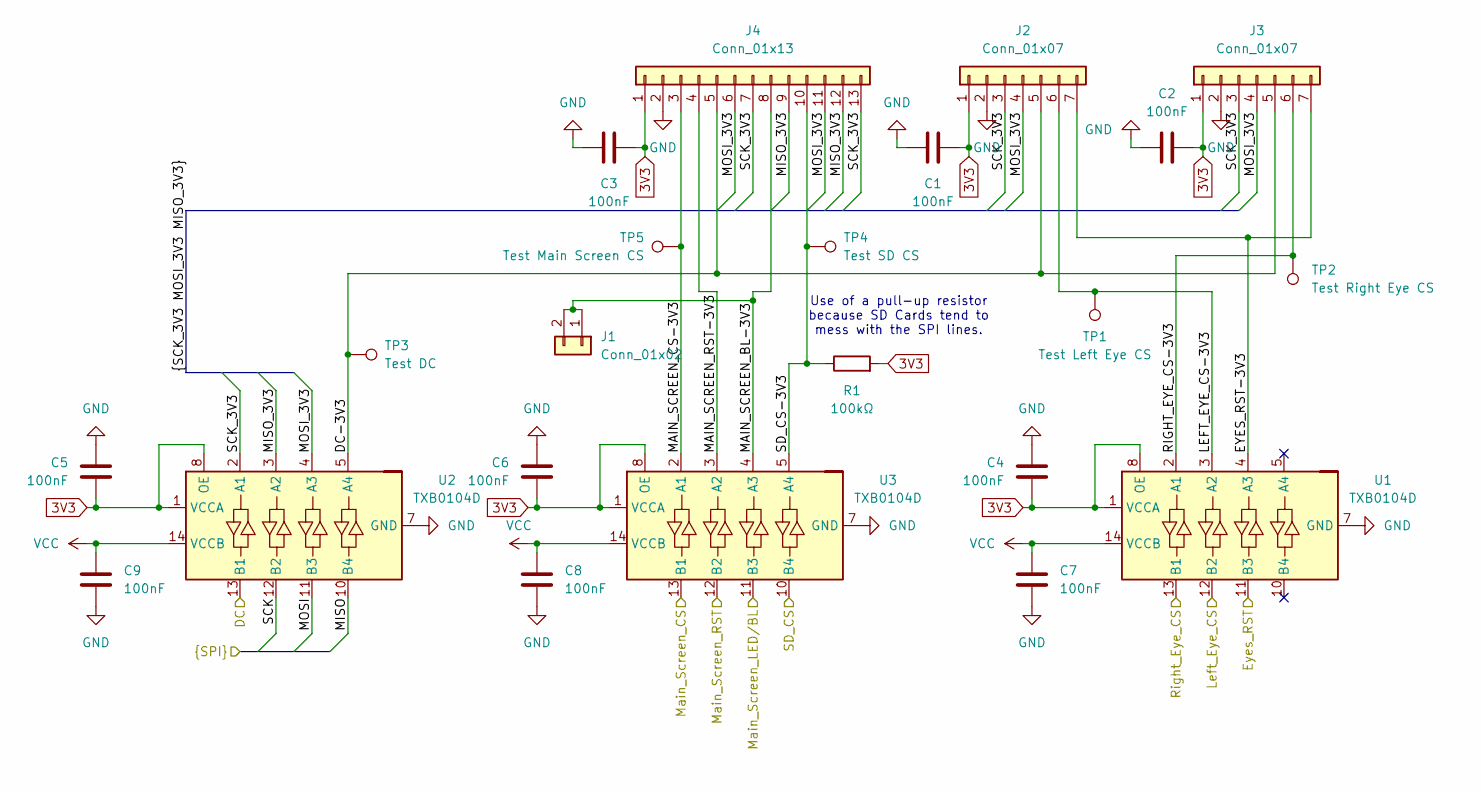
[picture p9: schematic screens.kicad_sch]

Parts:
C1, C2, C3, C4, C5, C6, C7, C8, C9: 100nF; Capacitor_0603; LCSC C14663
J1: Conn_01x02; JST XH 2 pins
J2, J3: Conn_01x07; Pin_1x07_2.54mm_Vertical
J4: Conn_01x13; Pin_1x13_2.54mm_Vertical
R1: 100kΩ; Resistor_0603; LCSC C2906980
TP1: Test Left Eye CS; Test point
TP2: Test Right Eye CS; Test point
TP3: Test DC; Test point
TP4: Test SD CS; Test point
TP5: Test Main Screen CS; Test point
U1, U2, U3: TXB0104D; SOIC-14_3.9x8.7mm_P1.27mm; LCSC C2652946

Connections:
3V3: C1.2, C2.2, C3.2, C4.2, C5.2, C6.2, J2.1, J3.1, J4.1, R1.2, U1.1 (VCCA), U1.8 (OE), U2.1 (VCCA), U2.8 (OE), U3.1 (VCCA), U3.8 (OE); also elsewhere on the board
/MISO: U2.10 (B4); also elsewhere on the board
/MOSI: U2.11 (B3); also elsewhere on the board
/SCK: U2.12 (B2); also elsewhere on the board
/Screens/DC: U2.13 (B1); also elsewhere on the board
/Screens/DC-3V3: J2.5, J3.5, J4.5, TP3.1, U2.5 (A4)
/Screens/EYES_RST-3V3: J2.7, J3.7, U1.4 (A3)
/Screens/Eyes_RST: U1.11 (B3); also elsewhere on the board
/Screens/LEFT_EYE_CS-3V3: J2.6, TP1.1, U1.3 (A2)
/Screens/Left_Eye_CS: U1.12 (B2); also elsewhere on the board
/Screens/MAIN_SCREEN_BL-3V3: J1.1, J1.2, J4.8, U3.4 (A3)
/Screens/MAIN_SCREEN_CS-3V3: J4.3, TP5.1, U3.2 (A1)
/Screens/MAIN_SCREEN_RST-3V3: J4.4, U3.3 (A2)
/Screens/MISO_3V3: J4.9, J4.12, U2.3 (A2)
/Screens/MOSI_3V3: J2.4, J3.4, J4.6, J4.11, U2.4 (A3)
/Screens/Main_Screen_CS: U3.13 (B1); also elsewhere on the board
/Screens/Main_Screen_LED/BL: U3.11 (B3); also elsewhere on the board
/Screens/Main_Screen_RST: U3.12 (B2); also elsewhere on the board
/Screens/RIGHT_EYE_CS-3V3: J3.6, TP2.1, U1.2 (A1)
/Screens/Right_Eye_CS: U1.13 (B1); also elsewhere on the board
/Screens/SCK_3V3: J2.3, J3.3, J4.7, J4.13, U2.2 (A1)
/Screens/SD_CS: U3.10 (B4); also elsewhere on the board
/Screens/SD_CS-3V3: J4.10, R1.1, TP4.1, U3.5 (A4)
GND: C1.1, C2.1, C3.1, C4.1, C5.1, C6.1, C7.1, C8.1, C9.1, J2.2, J3.2, J4.2, U1.7 (GND), U2.7 (GND), U3.7 (GND); also elsewhere on the board
VCC: C7.2, C8.2, C9.2, U1.14 (VCCB), U2.14 (VCCB), U3.14 (VCCB); also elsewhere on the board

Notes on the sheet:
Use of a pull-up resistor because SD Cards tend to mess with the SPI lines.

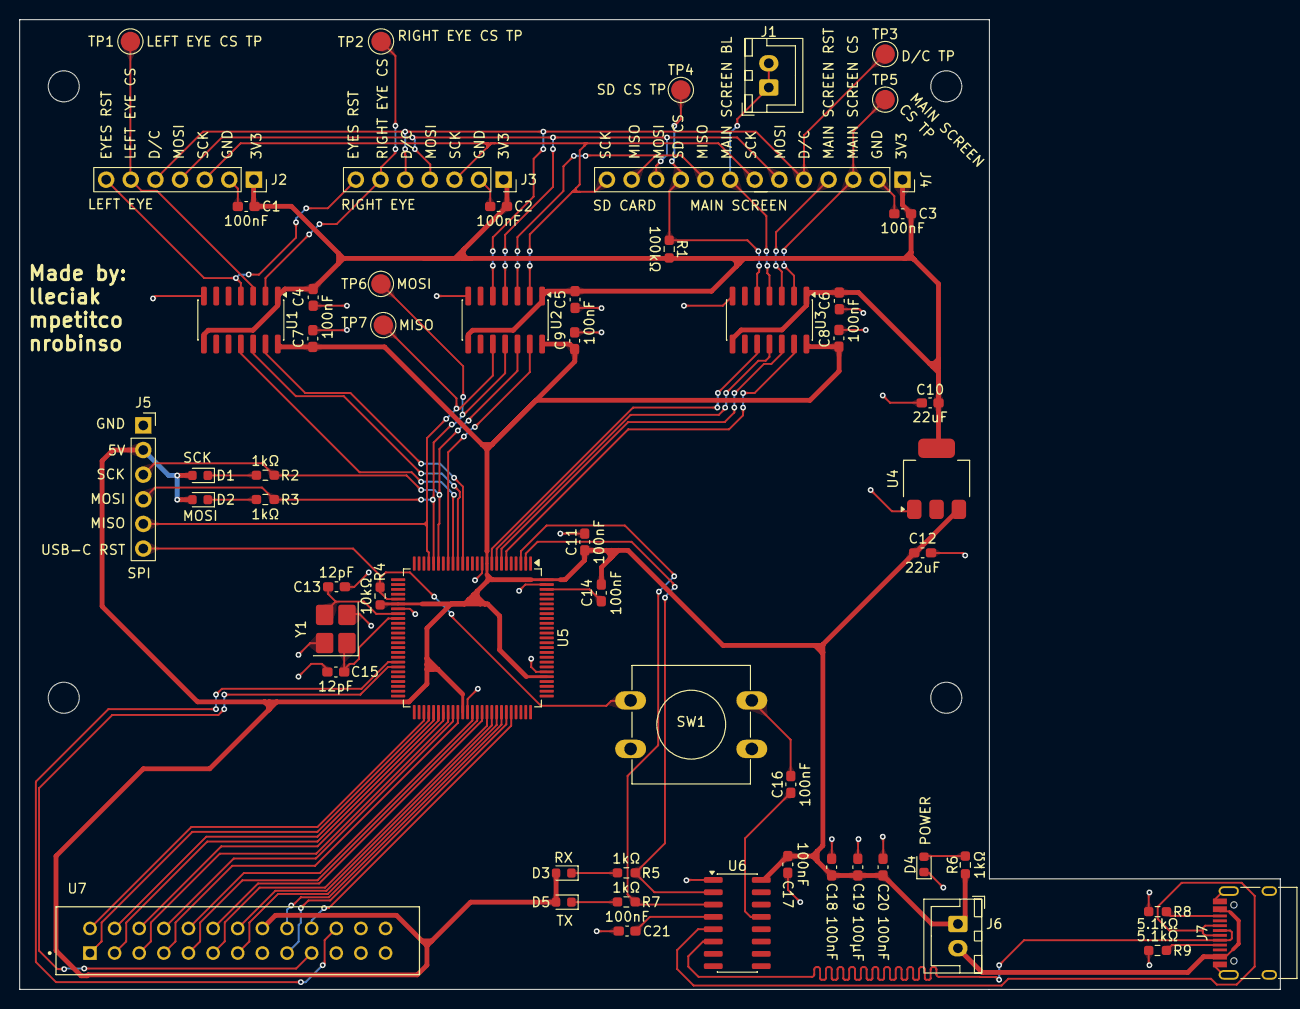
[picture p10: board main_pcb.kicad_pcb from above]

Board: 2 copper layers, 130.0 x 100.0 mm, 58 parts (0 on the bottom side), 62 nets.

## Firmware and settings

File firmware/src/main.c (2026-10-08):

#include <util/delay.h>

#include "app/alphabet.h"
#include "app/game.h"
#include "app/language.h"
#include "app/menu.h"
#include "display/GC9A01.h"
#include "input/i2c_rotary.h"
#include "input/keypad.h"
#include "input/rotary.h"
#include "system/globals.h"
#include "system/init.h"
#include "system/power_save.h"
#include "utils/keyboard_utils.h"

int main(void)
{
  init();

  GC9A01_fillScreen_eyes(GC9A01A_COLOR_GREEN);
  eyes_action();

  language_init();
  if (language == LANG_FR)
    show_bonjour();
  else
    show_hello();
  _delay_ms(300);
  show_menu();

  while (1)
  {
    language_update();
    random_update();
    rotary_update();
    rotary_button_update();
    power_save_update();
    // listening to the keyboard for the power save
    int key = keypad_read();
    if (key >= 0)
      power_save_activity();

    if (app_state == TRADUCTION && word_state == INPUT)
    {
      traduction();
    }

    else if (app_state == ALPHABET)
    {
      alphabet();
    }

    else if (app_state == JEU)
    {
      game();
    }
  }
  return 0;
}

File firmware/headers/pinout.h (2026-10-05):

#ifndef PINOUT_H
#define PINOUT_H

// I2C GENERAL
#define SCL (1 << PD0)
#define SDA (1 << PD1)

// SPI GENERAL
#define CS (1 << PB0)
#define SCK (1 << PB1)
#define MOSI (1 << PB2)
#define MISO (1 << PB3)

// SLAVE SELECTS (SPI)
#define MAIN_SCREEN_CS (1 << PH0)
#define LEFT_EYE_CS (1 << PE5)
#define RIGHT_EYE_CS (1 << PE7)
#define SD_CS (1 << PH5)

// RESETS (SPI)
#define EYES_RST (1 << PE6)
#define MAIN_SCREEN_RST (1 << PH1)

// SCREENS SPI GENERAL
#define SCREENS_DC (1 << PH6)

// MAIN SCREEN SPI
#define MAIN_SCREEN_BL (1 << PH2)

// KEYBOARD
#define KB_R1 (1 << PJ2)
#define KB_R2 (1 << PJ1)
#define KB_R3 (1 << PJ0)
#define KB_R4 (1 << PC7)

#define KB_C1 (1 << PA3)
#define KB_C2 (1 << PA4)
#define KB_C3 (1 << PA5)
#define KB_C4 (1 << PA6)
#define KB_C5 (1 << PA7)
#define KB_C6 (1 << PG2)
#define KB_C7 (1 << PJ6)
#define KB_C8 (1 << PJ5)
#define KB_C9 (1 << PJ4)
#define KB_C10 (1 << PJ3)

// ROTARY ENCODER
#define SDL_SW1 (1 << PC1)
#define SDL_SW2 (1 << PC2)
#define SDL_SW3 (1 << PC3)

#define MAIN_SCREEN_CS_LOW() (PORTH &= ~(MAIN_SCREEN_CS));
#define MAIN_SCREEN_CS_HIGH() (PORTH |= (MAIN_SCREEN_CS));
#define SD_CS_LOW() (PORTH &= ~(SD_CS))
#define SD_CS_HIGH() (PORTH |= (SD_CS))

#define MAIN_SCREEN_RST_HIGH() (PORTH |= (MAIN_SCREEN_RST))
#define MAIN_SCREEN_RST_LOW() (PORTH &= ~(MAIN_SCREEN_RST))
#define MAIN_SCREEN_BL_HIGH() (PORTH |= (MAIN_SCREEN_BL))
#define MAIN_SCREEN_BL_LOW() (PORTH &= ~(MAIN_SCREEN_BL))

#define DC_CMD() (PORTH &= ~(SCREENS_DC))
#define DC_DATA() (PORTH |= (SCREENS_DC))

#endif /* ifndef PINOUT_H */

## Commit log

2026-06-02 Adds more symbols to the symbol library (#11)
    feat(Symbol library): Adds the following symbols: GND, VCC, power flag, resistor, capacitor, voltage regulator, clickable rotary encoder, crystal, LED, SPDT slider switch, GC9A01A and regular pushbut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
2026-06-12 feat(ST7796): Adds datasheet for ST7796 screen driver. (#15)
2026-06-17 Adding text wrapping (#23)
    * feat(text wrapping): Changes background colour and uses string of text that needs wrapping to test text wrap feature.
    * feat(text wrapping): Encapsulates draw_char() function to try to make draw_string() more readable and starts trying to implement text wrapping.
    Text wrapping is a work in progress, problem is still not solved.
    * feat(text display): Adds wrapping. (Yes it's a gigantic commit, I was in the zone, I'm tired and don't really want to spend another couple of hours dissecting this commit into smaller ones... oopsie !)
    [main.c]
2026-06-18 Text wrapping refactor (#24)
    * feat(Text display refactoring): Moves the text related functions to their own source file and header. Encapsulated part of draw_n_char to have a more readable function (avoiding 5 level of nesting regarding the for loops)
    * feat(text display): Refactors a little bit, adds comments for the text displaying functions.
    [main.c]
2026-07-30 Adding schematic for Main PCB (MCU and screens) (#37)
    * feat(KiCad): Adds main PCB schematic
    [USB-C.kicad_sch, main_pcb.kicad_pcb, main_pcb.kicad_sch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]
2026-07-31 Adds Main PCB layout (#38)
    * feat(PCB): PCB first draft
    [USB-C.kicad_sch, main_pcb.kicad_pcb, main_pcb.kicad_sch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]
2026-08-05 Maddie/main pcb refactor (#39)
    * feat(PCB Layout): Refactors Main PCB layout to achieve smaller form factor and adds JLCPCB constraints.
    * feat(symbols): Adds 4pin crystal symbols and adds it to schematic
    * feat(schematic): Connects C2 and C3 to the crystal
    * feat(schematic): Revamps fully the circuit schematic
    * feat(schematic): Assigns footprints to symbols
    * feat(pcb): Alternative first draft
    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
    [USB-C.kicad_sch, crystal.kicad_sch, main_pcb.kicad_pcb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]
2026-08-26 Adds homebrew symbols for main PCB (#40)
    * feat(symbols): Adds Conn_01x01 symbol.
    * feat(PCB): Adjusts PCB mounting holes.
    * feat(symbols): Adds resistor and capacitor symbols.
    * feat(symbols): Adds Conn_01x06 symbol, adjusts pin length across all library symbols.
    * feat(symbols): Adds Conn_01x21 symbol.
    * feat(symbols): Adds connector symbols and AMS117-3.3.
    * feat(symbols): Adds CH340C symbol.
    * feat(symbols): Adds some more symbols (I don't remember which are new).
    * feat(symbols): Adds ATmega2560 symbol.
    * fix(symbols): Adjusts pin lengths for all symbols.
    * Oopsie; don't remember.
    * feat(symbols): Adds pin header symbols (7,13,21)
    * feat(symbols): Adds CH340C, TXB0104D, Capa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
    [USB-C.kicad_sch, crystal.kicad_sch, main_pcb.kicad_pcb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]
2026-08-31 Fixing mistakes on Screen PCB (#41)
    * feat(Symbols): Reviews all home-brew symbols
    * feat(footprintrs): Working on USB-C footprint
    * feat(schematic): Fixing mistakes
    [main_pcb.kicad_pcb, usb-c.kicad_sch]
2026-09-03 Unifying footprints (#42)
    * feat(KiCad libraries): Starts the reunification procedure
    * feat(KiCad libraries): Continues unification procedure
    * feat(Kicad Libraries): Continues footprint library unification, we're getting there soldier :)
    * feat(KiCad Libraries): Unification should be done !
    * chore(gitignore): Adds KiCad backups to list of ignored files
2026-09-11 Codebase v2 (#43)
    * chore: Moves all old code to backup, clean slate for src/ and headers/
    * feat(headers): Adds pinout and mask headers.
    * feat(test): Adds main.c with test code.
    * feat(test): Adds test code.
    * feat(Makefile): Adds Makefile
    * feat(headers): Updates pinout.h to add keyboard, I2C, etc. and removes masks.h
    * feat(code): Tests the newly soldered PCB ! It's working, well done ! :)
    * Port wrong for pin 12 and 60
    * feat(codebase): Saves work, screens not working yet
    * Starting working on LCD_eye_Right
    * Changing defines to match pins
    * started working on eyes Lib init()
    * LCD Round fond color working
    * Nothing works with CS pins
    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
    [main_pcb.csv]
2026-09-12 added functions to write to both eyes and speed up SPI bus (#45)
2026-09-14 Lleciak.keyboard (#47)
    * feat: start of a 2x3 keyboard matrix, not working rn
    * add: working code for 1 button, displayread, displaywrite and pinmode are working
    * fix: code now works with a matrice
    * add: working code for 40 buttons, 4x10 matrice, one with the original pinout, one with a pinout for the arduino
    * add: working code for the rotary encoder, display number that increment or decrement, the button function is working
    * fix: not really an issue but cleaned a bit the code
    * add: clean code working with a menu for rotary, not i2c
    * fix: changed the pinout for the keyboard part
    * fix: changed com
    * add: slide switch code, white or blue led turn on, worked once and is broken n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
    [keyboard.kicad_pcb, keyboard.kicad_sch, keyboard_gerber_bom.csv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]
2026-09-15 Louscreen (#49)
    * add: set up experimentation
    * new eyes
    * started test for rotary + screen
    * add: we can change eyes using the rotary encoder !!!
2026-09-15 Main PCB v2 (#51)
    * feat(schematic & pcb): Switches to 2 rows header for keyboard connection
    * feat(pcb): Keeps working on version 2 of main PCB
    * feat(PCB): Continues work on PCB v2.
    * feat(PCB): Continues work
    * feat(PCB): Continues work
    * feat(pcb): Workinonit
    * feat(footprints): Adds homebrew USB-C
    * chore(migration): Migrates to homebrew symbols for PCB.
    * feat(footprints): Reworking footprints to allow hand-soldering
    * feat(pcb): I think that's about right
    * feat(pcb): Should be a-ok
    * feat(PCB): Adds two pins header for LED Backlight
    * feat(pcb): Uses new footprint for Male Header 2x13
    * feat(3D models): Adds 3D models to PCB
    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
    [69830-026LF--3DModel-STEP-533217.STEP, XG4C-2631--3DModel-STEP-273799.STEP, crystal.kicad_sch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]
2026-09-18 SD Card initialisation over SPI (#52)
    * feat(crc): Adds CRC7 algorithm.
    This algorithm will be used to communicate with the SD Card at its startup
    * feat(sd): Starts implementing SD mode commands to switch to SPI
    * feat(Makefile): Adds sd an crc7 files to sources
    * feat(sd): Continues work on SD Card implementation
    * feat(sd): Finishes SD initialisation
    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
2026-09-18 feat(GitHub actions): Improves current "Firmware Build" actio action (#53)
    * feat(GitHub actions): Improves current "Firmware Build" actio action
    * feat(GitHub Actions): Fixes small owner issue
    * feat(GitHub Actions): Fixes owner issue
2026-09-23 Lleciak screen (#56)
    * fix: change pinout from the arduino one to the homemade pcb one
    * add: letter on the screen with our keyboard !!!
    * add: enter a word and validate it
    * add: menu working with clean cursor
    * add: init.c and globals.c/.h
    * add: clean main, one issue to fix but cleaner code in src/experimentation
    * kicad = misogyne
    * fix; eye_imgs declaration
    * add: power save mode and delete button now works
    * clean: added some comments
    [keyboard.kicad_sch]
2026-09-25 Lleciak.feat (#58)
    * add: setup language and slide switch
    * add games
    * fix: save power pb
    * add: started trad and game 1 is working
    * clean: move traduction ft from menu.c to traduction.c
    * add: alphabet, start of game 2 and cleaned up rotary code
    [alphabet.c, game.c, i2c-rotary.c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]
2026-09-25 Adding SD Card operation and FAT32 file system navigation (#57)
    * feat(SD/FAT32): Checkpoint, tu-du ! :)
    * feat(sd): Fixes SD bug on cold boot.
    SD Card had issues to initialise correctly on cold boots, adding a loop with some timeouts in sd_init() fixed it.
    * feat(compliance): Substitutes standard memcpy() for homebrew version.
    In order to comply with the "no external libraries" rule, ft_memcpy has been implemented in order to replace the standard memcpy() function.
    * feat(FAT): Adds and refactors FAT file system implementation.
    * chore: Cleaning old fatfs.c/h locations
    * feat(scope): Moves somes definitions to header so as to be available for other source files
    * feat(sd): Adds SD h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
    [bmp.c, fatfs.c, ili9488.c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]
2026-09-25 Fusion (#60)
    * try: fixing img pb
    * fix: Fixes cyclical header includes directives causing compilation error
    * not working and workinonit
    * feat(SD streaming): Fixes address passed to sd_stream_to_screen() and fixes logic to redisplay menu after displaying sign in alphabet mode
    * chore: .clang-format break after braces set to true
    * add: _LSF and _BSLworking both with alphabet
    ---------
    [alphabet.c, bmp.c, fatfs.c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]
2026-09-25 Maddie/cleanup (#61)
    * chore: Cleanup
    * feat: Adds subject
    * feat(Makefile): Adds default value for PORT variable
    If you need, create a config.mk file and write this inside
    PORT := <YOUR_PORT>
    for instance:
    PORT := /dev/ttyUSB0
    * feat(Makefile): Adds root Makefile
    * fix: Updates GitHub action to reflect changes made to repo structure
    [69830-026LF--3DModel-STEP-533217.STEP, XG4C-2631--3DModel-STEP-273799.STEP, crystal.kicad_sch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]
2026-09-25 Adds Linting to the CI pipeline + small globals fix (#65)
    * feat(Lint): Adds lint GitHub action and lint / fix-lint rules in Makefile
    * fix: Fixes globals missing extern qualifyers
    [alphabet.c]
2026-09-29 Maddie/speeding up display & UART debug prints (#66)
    * feat(prints): Adds some initialisation UART prints and moved some to debug mode only.
    Debug mode is toggled by compiling with -DDEBUG, which is done with make debug
    * chore: Moves somes more UART prints to debug mode.
    * feat(debug): Moves some more UART prints to debug mode only
    * chore: Trying to figure out what prints shouold be in debug mode only
    * chore: Adds UART debug prints (might be a bit too much)
    * fix: Fixes variable set but not used warning
    * chore: Removes unnecessary calls
    [alphabet.c, bmp.c, fatfs.c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]
2026-10-05 Lleciak.img (#68)
    * fix: game 2 no more send you to game 1 after one answer
    * fix: game1, cursor back to 0 when you give an answer
    * add: game1 works with images now
    * add: game 2 works with img !
    * fix: No more double when you start in english
    * fix: ++ since last commit trad works with img
    * clean: removed some deprecated coms
    * add: language_init to avoid the double menu print pb
    * add: eyes are closing sometimes, still a pb when you want to do something at the same time
    * add: readme
    * add: readme typo
    * add: english version of the readme
    * add: small info in readme.md
    * fix: linter
    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
    [GC9A01.c, alphabet.c, game.c]
2026-10-05 ILI9488 Code refactoring (#67)
    * Chore: Fixes typos and obsolete names
    * feat(refactor): Moves files around, prepares main_screen.h deletion
    * feat(refactor): Removes main_screen.c
    ili9488.c/h still need to be tidied
    * feat(refactor): Tidies ili9488.c/h
    * Lleciak.img (#68)
    * add: eyes are closing sometimes, still a p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
    [alphabet.c, game.c, ili9488.c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]
2026-10-05 iBOMs for PCBs v2 (#70)
    * feat(memory optimisation): Reduces flash memory and SRAM footprint
    * feat(iBOM): Adds main screen and keyboard iBOM
2026-10-05 feat(memory optimisation): Reduces flash memory and SRAM footprint (#69)
2026-10-05 fix: Swaps window end dimensions for sd_stream_bmp_to_screen() (#71)
    [sd_streaming.c]
2026-10-06 Keyboard pcb fix (#74)
    * fix: Fixes push button switch footprint pad assignation
    * fix: Fixes rotary encoder footprint pad assignation
    * fix: Reannotates schematic components
    * fix: Reworks keyboard PCB
    * chore: KiCad updates
    * chore: keyboard PCB review done
    * fix: Numerotation fix
    * chore: Adds some 3D models
    [keyboard.kicad_pcb, keyboard.kicad_sch]
2026-10-08 Lleciak.littlefix (#75)
    * fix: remove the fill screen between each letter
    * add: balise where i need to fix smthng, need a working pcb to test it
    * add: start image
    * fix: game assets name, input when sleeping, eyes closing the right way when sleeping
    * typo
    [alphabet.c, fatfs.c, game.c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]
2026-10-08 Sd multiple sectors fix (#76)
    * feat(sd card): Programs now reads several FAT cluster instead of just the first one
    * feat(fat file system): Adds comments and defines to the fatfs implementation to read several clusters
    [fatfs.c]
2026-10-08 fix game and add hello img when you switch language (#77)
    [game.c, language.c]
2026-10-08 fix: cursor pb in games (#78)
    [game.c]
2026-10-09 Repo tidying (#79)
    * chore: Removes unnecessary KiCad files, updates gitignore
    * chore: Updates gitignore to ignore KiCad backup archives
    * chore: Repo tidying
    * chore: Tidying
    [69830-026LF--3DModel-STEP-533217.STEP, XG4C-2631--3DModel-STEP-273799.STEP, crystal.kicad_sch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]
2026-10-13 fix: double print when you cold start in bsl (#84)
2026-10-13 Maddie/power save enhancement (#85)
    * feat(power saving mode): Adds sleep in/out for main screen
    * feat(power save): Fixes white flash when going out of sleep mode
    * fix: Switches INACTIVITY_THRESHOLD back to 30000
2026-10-15 Added the 3d casing files, so technically you could print one (#91)
2026-10-15 Maddie/main pcb schematic cleaning (#88)
    * feat(main PCB): Reworks schematic
    * feat(main PCB): Removes no longer used BL pin 01x02 header
    * feat(main PCB): Fixes main PCB routing issue
    * chore: Reworks main PCB schematic/PCB
    * chore: Removes old csv file
2026-10-15 Screen fix for PCB v2 (#87)
    * Fix: Pinout for protov2
    * Fix: Solves crosstalk issue on ribbon cable lines (fix is also hardware)
    * Chore: Cleaning test instructions
    * Chore: Cleaning test instructions
2026-10-15 Fix: Re-fixes pinout and silkscreen (#93)
2026-10-15 Add.pcb.imb (#94)
    * add: PCB pictures
    * rename: picture in 3d modele
2026-10-15 Theme switching ! (#95)
    * feat(colour theme): Adds macro to be able to switch color palette easily
    * feat(Colour theme): Better marco definition else/if
    * Feat(update script): Adds update.sh to easily update
    * feat(Themes): Adds a way to build all hex files for each themes easily
    * Fix: Fix GitHub Actions
2026-10-15 Fix: Switches game answer feedback colour back to hardcoded colours (instead of FG/BG/etc.) (#103)
2026-10-19 clean kicad directory (#115)
2026-10-19 fix: swaps CH340C because KiCad keeps swapping it for the default one (#127)
